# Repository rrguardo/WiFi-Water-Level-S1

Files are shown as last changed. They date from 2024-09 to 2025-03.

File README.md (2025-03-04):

# WiFi Water Level S1

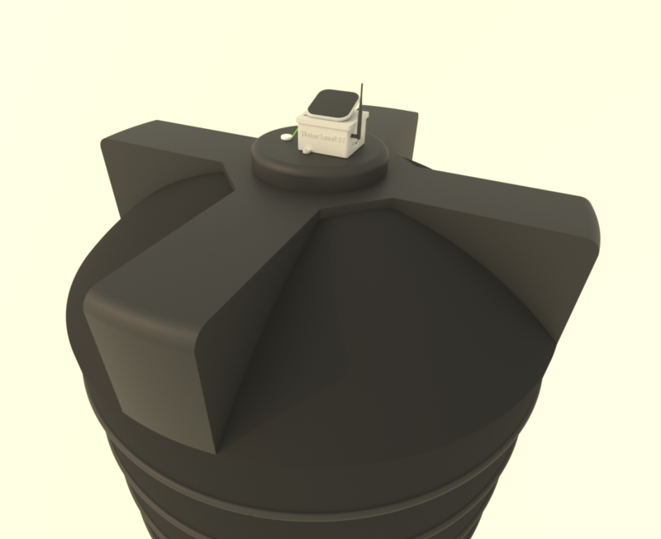
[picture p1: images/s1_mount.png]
WiFi Water Level S1


The **WiFi Water Level S1** is an advanced water level monitoring device designed to deliver precise
measurements for various applications, including tanks, wells, and reservoirs. 
Utilizing WiFi connectivity, it enables real-time monitoring and management of water levels from anywhere via a 
smartphone or computer. Powered by **solar energy**, the device is completely
wireless and autonomous. 

The system is cloud-connected, requiring an internet connection, and is designed for reliable, continuous operation.
For more details, refer to the [full features page](https://waterlevel.pro/products/WiFi-Water-Level-S1).

Additionally, it integrates seamlessly with the [WiFi Smart Water Pump Controller S1](https://github.com/rrguardo/WiFi-Smart-Water-Pump-Controller-S1), allowing for 
automatic control of a water pump based on the sensor's data. This integration enhances the system's 
efficiency by automating water management processes.

The project is open source and open hardware, licensed under GPLv3. All hardware, software, and
3D printable components were designed from scratch by me, **Raul Rodriguez Guardo**, and are released 
under the GPLv3 license, allowing for free use and modification.

<div style="display: flex;">
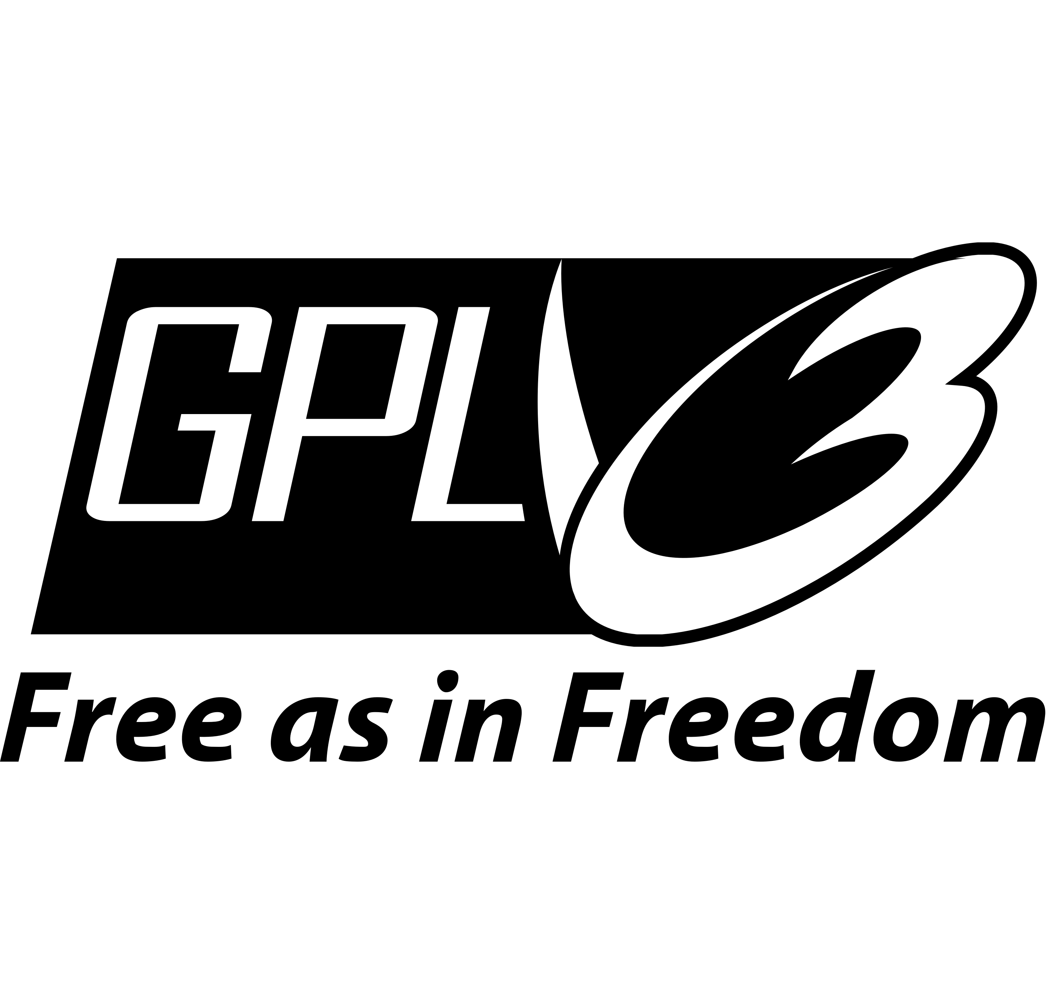
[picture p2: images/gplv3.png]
  
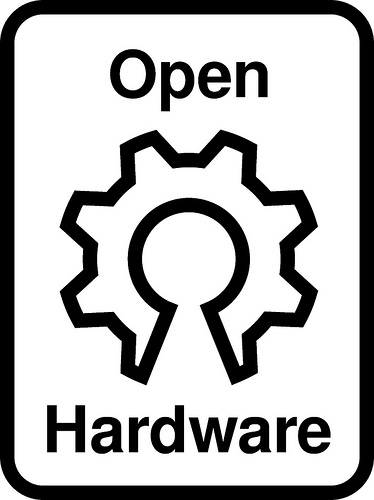
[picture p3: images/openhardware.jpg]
Imagen 1
  
</div>

[Real S1 Device Demo](https://waterlevel.pro/device_info?public_key=demo)

<div style="display: flex;">
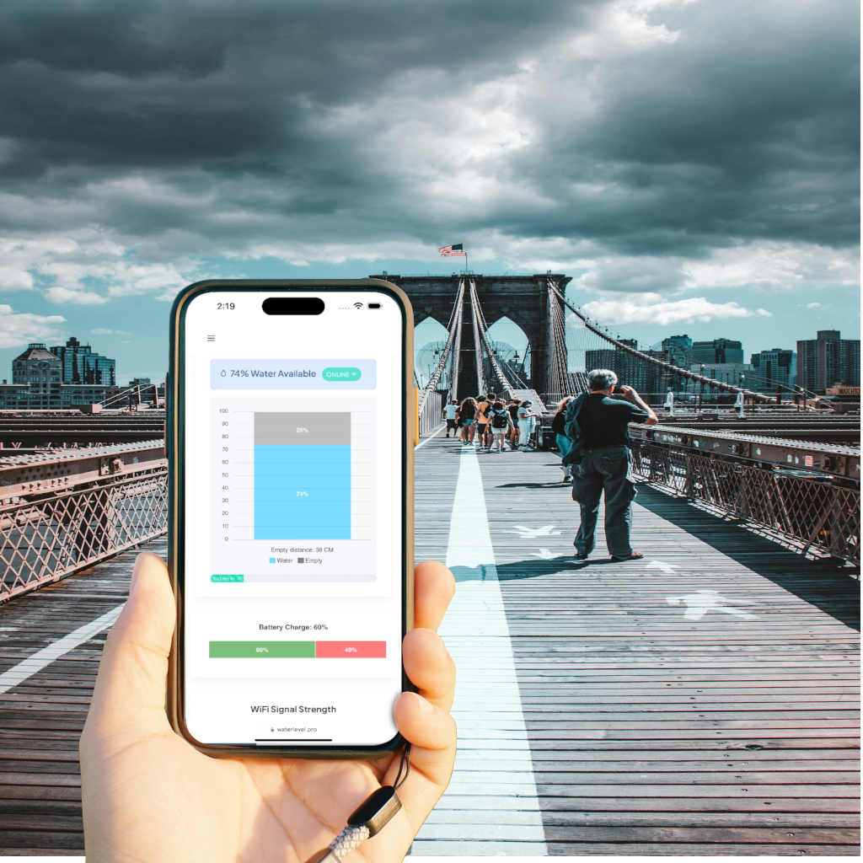
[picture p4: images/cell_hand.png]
  
</div>

### Device Compatible Sensors

* All **HCSR04** sensors family, that can work with **3.3V**
  *   **AJ-SR04M** recommended for water tanks or places of extreme humidity.
  *   **RCWL-1670** is compatible, but will need special waterproof case, if will be placed inside water tanks. 
* UART Distance sensors , that can work with **3.3V** (Not tested yet, experimental)
  *   **A02YYUW** recommended for water tanks or places of extreme humidity. 
  Offer a range of 3-450 CM, with an small 3 CM blind area.

**Note:** UART sensors have not been tested with this device yet and are currently in the experimental phase. 
To enable UART (A02YYUW), add or uncomment `#define UART_SENSOR`. Refer to the schematic or the PCB layout image 
to identify the RX/TX pins.

### Device Compatible Solar Panels

* Tested with 5.5 V, 130 mA Solar Panel (5.5V 130mA 72x72mm) https://www.aliexpress.us/item/3256804502745527.html using D1 5V zener. 
* Don't use solar panels that pass the 250 mA or 5.5V

## DIY Guide

For a detailed guide on how to build this project, check out the full tutorial at [Instructables](https://www.instructables.com/Build-Your-Own-DIY-WiFi-Water-Level-Sensor-S1/).

## Microcontroller Software

[ArduinoIDE INO File](WiFiWaterLevelS1/WiFiWaterLevelS1.ino)

This devide use ESP32-C3 microcontroller can use Arduino IDE to flash/upload microcontroller code, using **ESP32C3 Dev Module** as board.

[Download Latest Firmware Builds Here](WiFiWaterLevelS1/firmwares/)

## Server Side Minimal Sample in Python

Note [WaterLevel.Pro](https://waterlevel.pro/) offer a more advanced server side service free, 
but you can make your own server using the sample provided as a minimal sample. 

[Server sample that process and show sensor data](demo_server.py)

Pending TODO: Improve the opensource Server Side Minimal Sample UI.

---

## Hardware part at OSHWLab

[SunBuddy-C3 Module](https://oshwlab.com/rrguardo83/water-level-.pro-s1-v2)

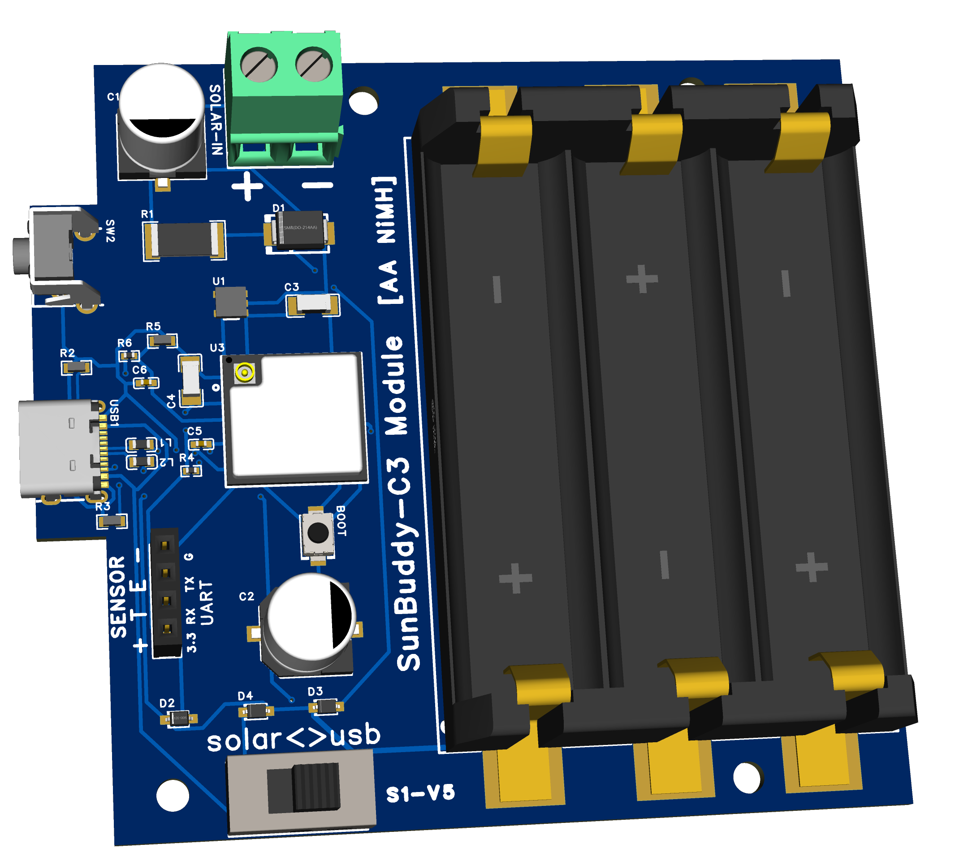
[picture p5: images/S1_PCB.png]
S1 PCB


### Where buy the PCB board?
[At EasyEDA project](https://waterlevel.pro/short/sunbuddy)
editor click **Order** menu.

### PCB Component Roles Diagram

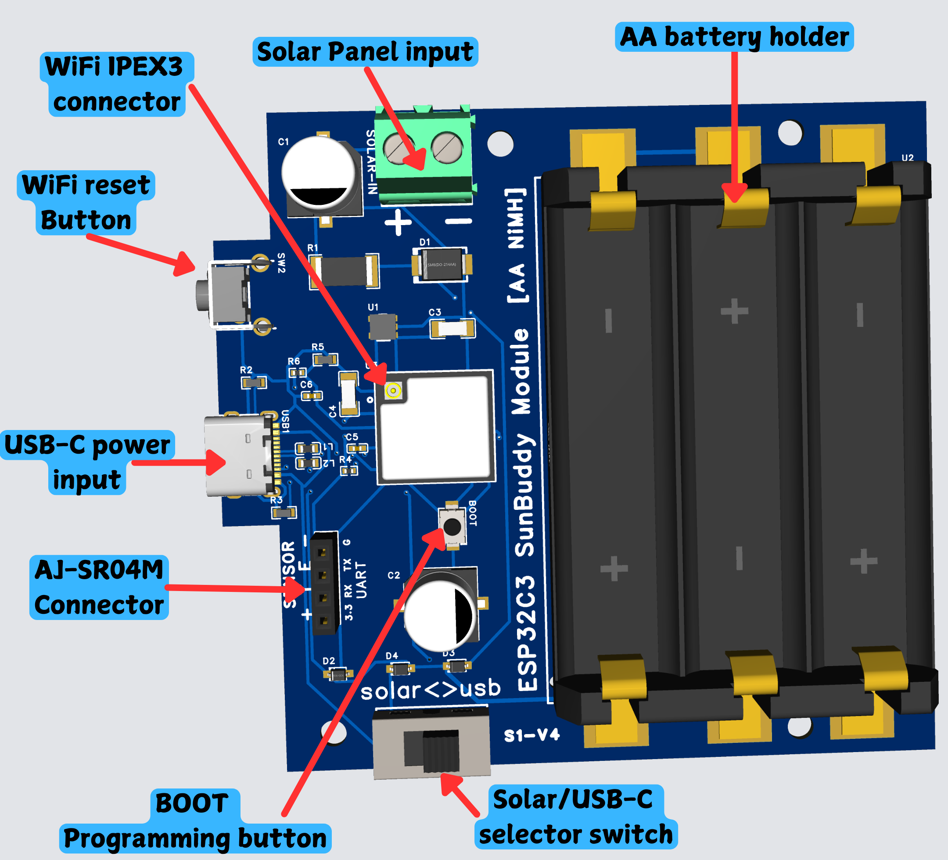
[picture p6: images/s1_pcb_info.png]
S1 PCB Features


---
## FreeCad 3D printable case components

[3D printable case components](3dcase)

For more details about important 3d printing recommendations 
 [read this tips](3dcase/3DPrintReadme.md).

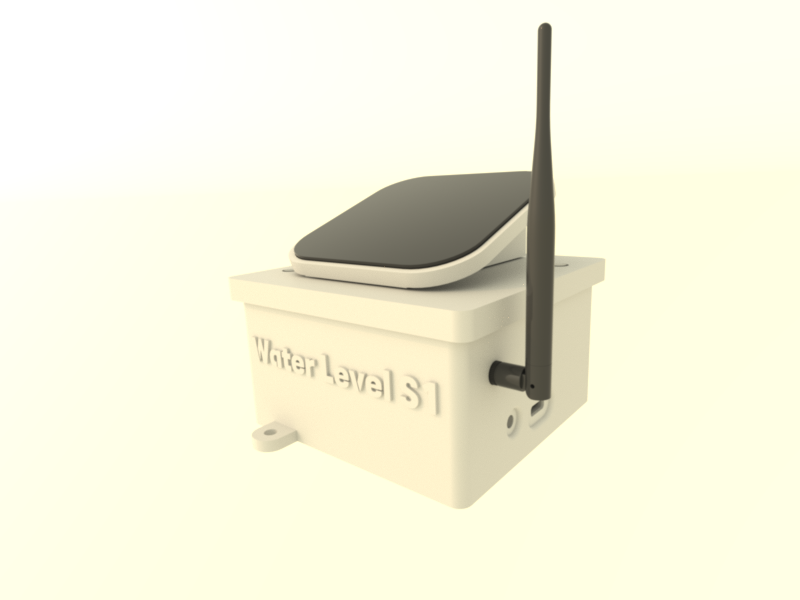
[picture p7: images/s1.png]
s1 open


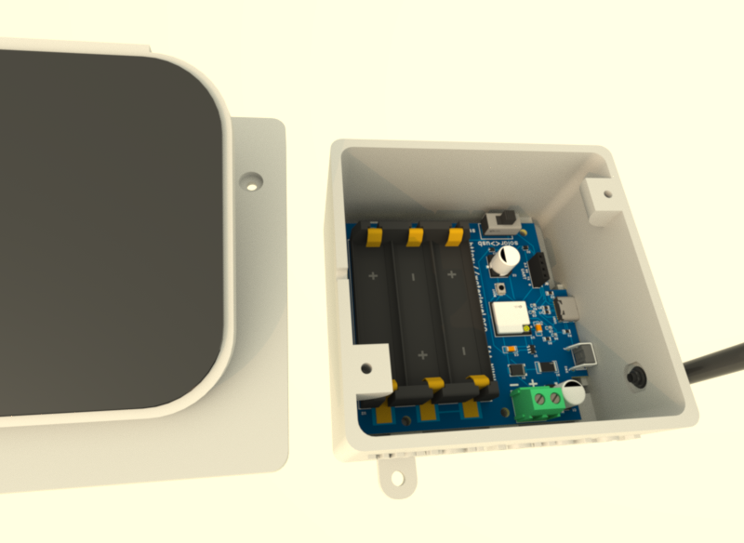
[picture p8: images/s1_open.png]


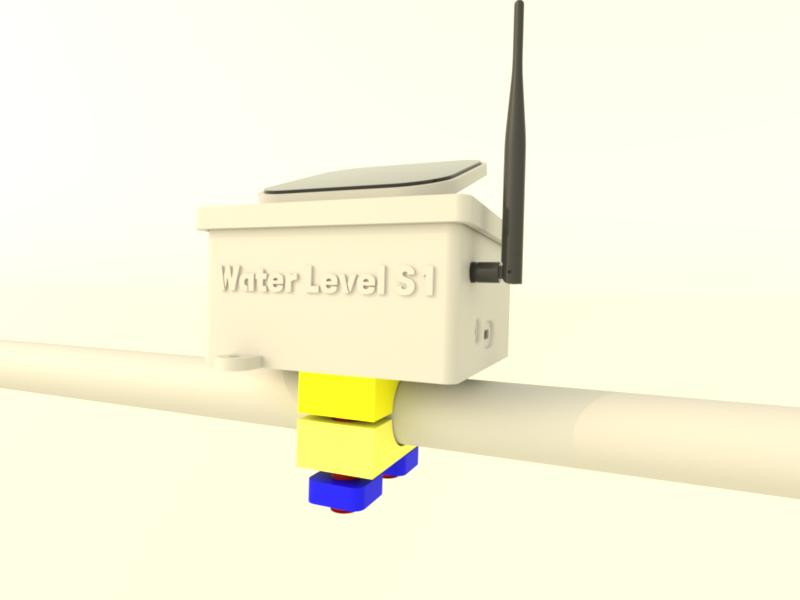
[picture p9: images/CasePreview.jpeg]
Top View


Bottom View

### No 3D Printer? No Problem! Easily Print Parts Using Online 3D Printing Service

| **3D Print Provider** | **Recommended Materials for Outdoors** | **Approximate Price** | **Print Quality** | **Delivery Options** | **Comments** |
|---|---|---|---|---|---|
| **JLCPCB (JLC3DP)** | Nylon (PA12) | Low to Medium | High for resin and MJF | International, economical | Great value for money, lacks PETG or ASA options |
| **Shapeways** | Nylon, Stainless Steel, Aluminum | Medium to High | Very high, detailed | International, fast | Ideal for high-detail projects and outdoor durable parts |
| **Sculpteo** | Nylon (PA12), Aluminum, Carbon-Reinforced Nylon | Medium | High | International, fast options | Wide range of materials, good for durable prototypes |
| **3D Hubs** | PETG, ABS, Nylon, Carbon Fiber-Reinforced Materials | Medium | High, varies by local provider | International, varies | Global network, quality and delivery times vary by provider|
| **Craftcloud** | PETG, Nylon, ASA, Carbon Fiber-Reinforced Materials | Medium | High, varies by provider | International, varies | Service aggregator, good price comparison across providers |
| **Materialise** | Nylon (PA12), Carbon-Reinforced Nylon, Metals | High | Very high, industrial focus | International, fast | Focus on industrial and professional applications |
| **Xometry** | Nylon, ABS, PETG, Aluminum, Carbon-Reinforced Nylon | Medium to High | Very high, professional focus | International, fast | Ideal for custom manufacturing and durable industrial parts|

Choose durable materials like **PETG** for outdoor use, and set **infill at 60%** or higher for added strength. Just upload the 3D files and get everything printed and shipped to you!

---
## Mount options samples
### Pipe mount
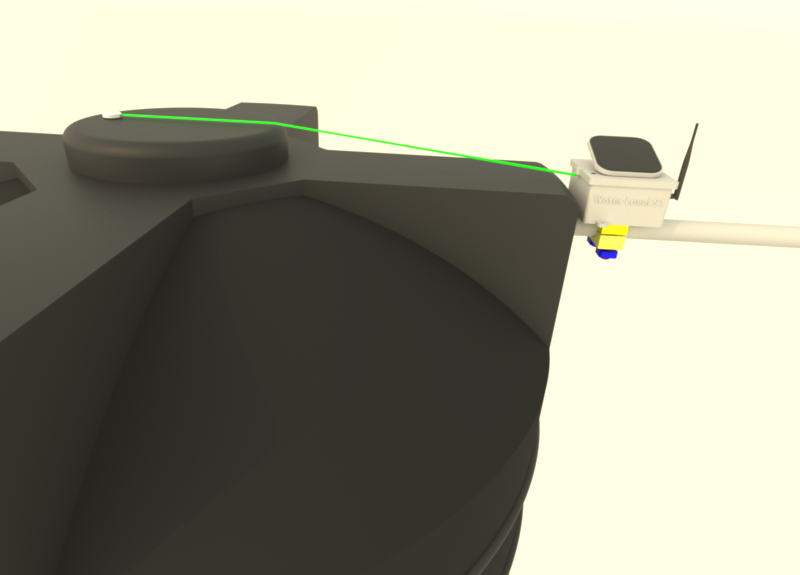
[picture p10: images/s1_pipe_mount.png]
Pipe Mount


### Water tank lid mount
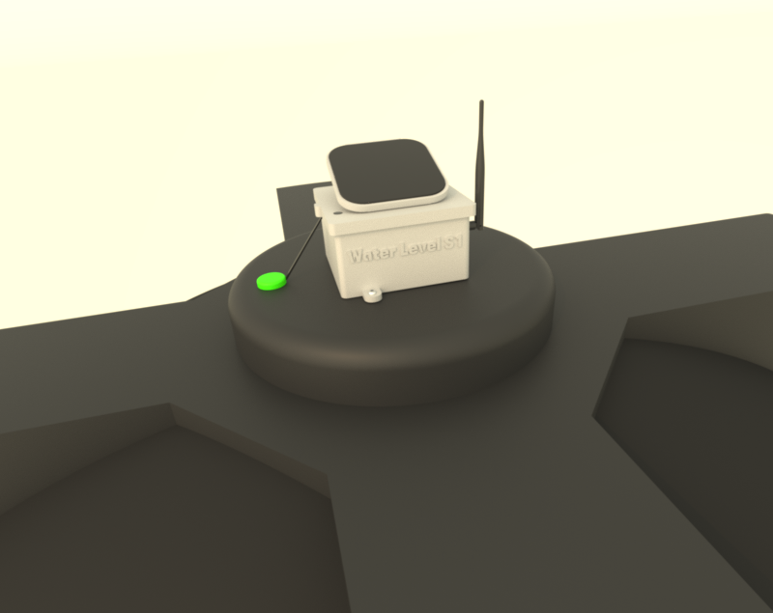
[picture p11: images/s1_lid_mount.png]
Lid Mount


---
## User Installation Manual

The [installation manual](https://waterlevel.pro/manuals/WiFi-Water-Level-S1) provides 
detailed instructions on setting up the WiFi Water Level S1. 
Be sure to [read all instructions](https://waterlevel.pro/manuals/WiFi-Water-Level-S1) 
carefully before proceeding with the installation to ensure proper 
setup and functionality.

[WiFi Water Level S1, Installation Manual](https://waterlevel.pro/manuals/WiFi-Water-Level-S1)

---

## What parts are opensource?

* All the hardware part
  * Electronics part: PCB, schematic.
  * Printable 3D Case
* Firmware software
* [Server sample that process and show sensor data](demo_server.py)

The server side implementation at https://waterlevel.pro/ (cloud services) that use the device are not 
included in this project or git repo and are not opensource.

---

## Next TODO:

* Add basic DIY Guide
* Improve the opensource server sample
  * UI
* ...

---

## Important Disclaimer

> **Disclaimer:**  
This open-source electronics project/device is provided strictly for experimental, educational, and developmental purposes. It is offered "as is," without any warranties, express or implied. This includes, but is not limited to, implied warranties of merchantability, fitness for a particular purpose, or non-infringement.
> 
Users are solely responsible for ensuring that the use of this device complies with local laws, regulations, and safety standards in their region.

---

<div align="center">
  <h5>Designed in the Dominican Republic 2024-2025</h5>
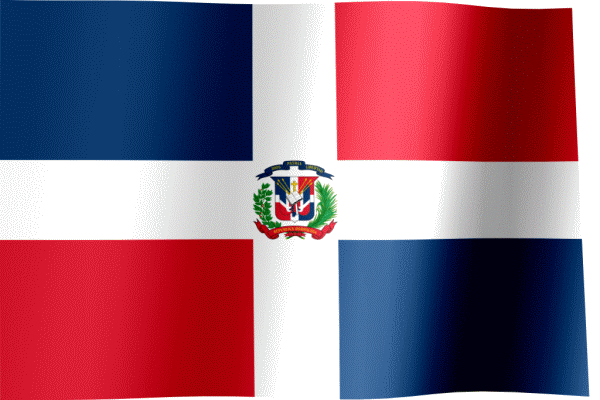
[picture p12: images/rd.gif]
RD
  
</div>

---

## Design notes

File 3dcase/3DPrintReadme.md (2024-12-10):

# Recommendations for Printing an Outdoor Case

To ensure that a case designed for outdoor use is durable and resistant to environmental conditions, follow these guidelines for various types of 3D printers and filaments:

## FDM Printers with PETG

**PETG** is a great choice for outdoor applications due to its resistance to UV light and moisture. Follow these settings for optimal results:

### Layer Height
- Use a smaller layer height (e.g., 0.2mm) to ensure finer details and better strength.

### Infill Density
- Set the infill density to at least 50% to provide adequate strength and durability. For high-impact areas, consider increasing to 100%.

### Wall Thickness
- Increase wall thickness (e.g., 4 to 6 walls) to enhance the structural integrity of the case and improve resistance to physical impacts.

### Cooling
- Use minimal cooling to prevent warping and ensure strong layer bonding.

### Annealing
- Consider annealing the printed case to improve strength and durability. This process can enhance PETG’s resistance to environmental factors.

## Other Types of Printers and Filaments

### SLA/DLP Printers
- **Resin**: Use UV-resistant resin for better durability against sunlight and weather conditions.
- **Settings**: Follow manufacturer recommendations for curing times and temperatures to ensure optimal print quality and resistance.

### SLS Printers
- **Nylon (PA)**: Use nylon, as it offers good resistance to UV light and moisture. It is also known for its toughness.
- **Settings**: Follow specific printer and material guidelines for temperature and print settings.

### High-Performance Materials
- **ABS**: For a more traditional choice, ABS can be used if UV resistance is not a primary concern, but it may require additional post-processing for outdoor use.
- **Polycarbonate (PC)**: This material provides excellent impact resistance and can withstand extreme temperatures, making it suitable for harsh environments.

## Sealing and Assembly Tips

- **Silicone Adhesive**: Use silicone adhesive or a glue gun with silicone sticks to seal and protect the case. Apply silicone to seal connectors, buttons, cables, and other openings to prevent moisture ingress and improve overall durability.
- **Sealing Joints**: Ensure that all seams and joints are properly sealed with silicone to protect against water and humidity.

## General Tips
- **Post-Processing**: Consider applying a UV-resistant coating or paint to further enhance protection against environmental elements.
- **Sealing**: Ensure that all seams and joints are properly sealed to prevent water ingress.

By following these recommendations, you can create a durable and resilient case suitable for outdoor environments.

---

# Recommendation for Printing Screws with PETG

To achieve the best results when printing 11mm diameter screws using FDM printers or other types of 3D printers with PETG filament, follow these guidelines:

## Layer Orientation

- Print the screws in a vertical orientation to ensure better definition of the threads and channels. This position can also facilitate faster printing with a 0.6mm nozzle, which is capable of producing high-quality prints efficiently.

## Layer Height

- Use a smaller layer height (e.g., 0.1mm to 0.2mm) for finer details and improved layer adhesion.

## Infill Density

- Set the infill density to 100% to ensure maximum strength and durability of the screw.

## Wall Thickness

- Increase the wall thickness (e.g., 4 to 6 walls) to enhance the structural integrity of the screw and prevent layer separation.

## Cooling

- Minimize or turn off the cooling fan to prevent layer delamination and ensure strong layer bonding.

## Annealing

- Consider annealing the printed screws to further improve their strength and layer bonding. This process enhances the mechanical properties of PETG, making the screws more durable.

## Nozzle Size

- A 0.6mm nozzle can be used to print the screws quickly and effectively while still achieving good thread definition. Ensure the print temperature is increased to improve layer adhesion and overall quality.

By following these guidelines, you can enhance the performance, durability, and precision of 11mm diameter screws printed with PETG filament.

---

## Other details
*  Solar lid is divided in 2 parts **SolarLid.stl** and **SolarSupportV2.stl**, use silicon glue to join the 2 parts.
* ...

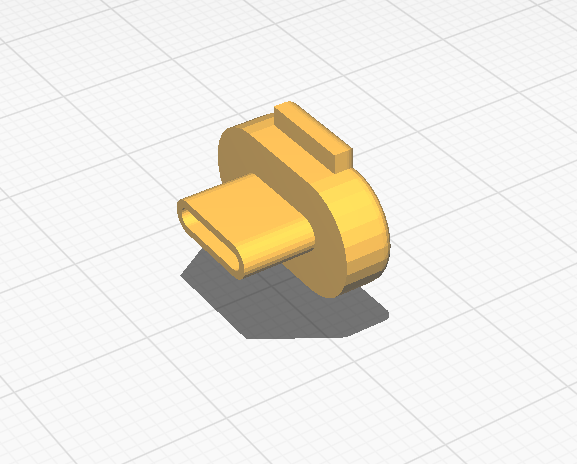
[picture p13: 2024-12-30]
images/usbc_cap.png

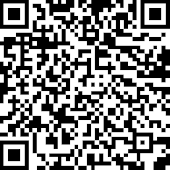
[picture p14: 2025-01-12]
images/eth_donations.png

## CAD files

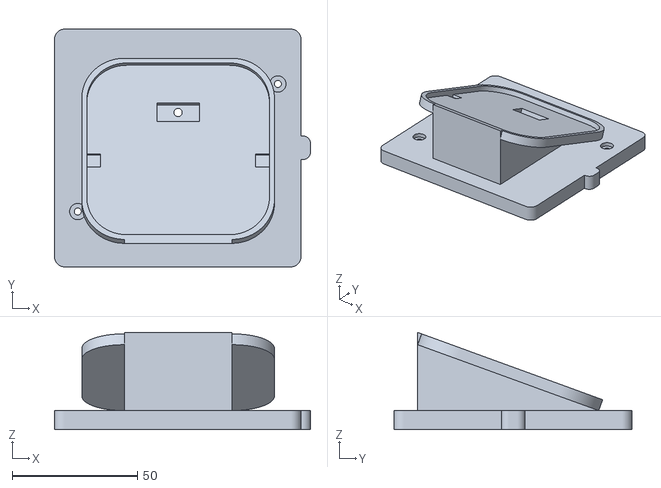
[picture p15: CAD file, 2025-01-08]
3dcase/LidSolarFusion.stl
102.3 x 95.0 x 38.8

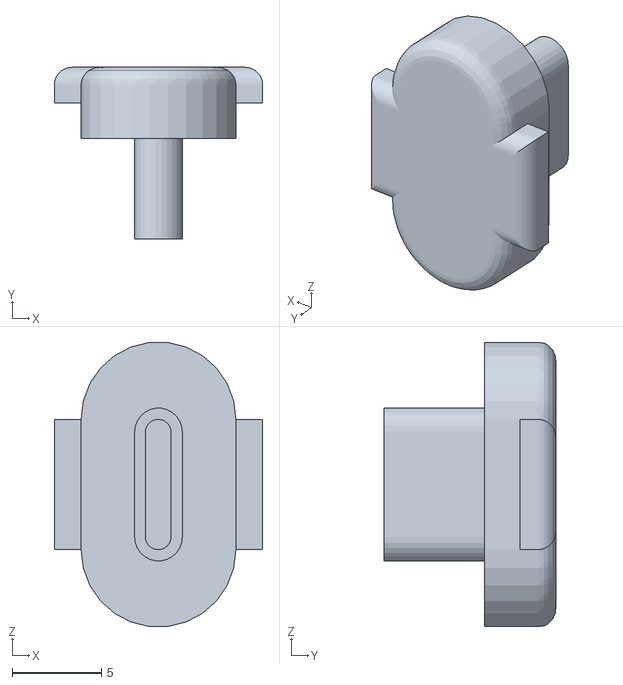
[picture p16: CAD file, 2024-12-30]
3dcase/USBC_CAP.stl
11.7 x 9.60 x 15.9

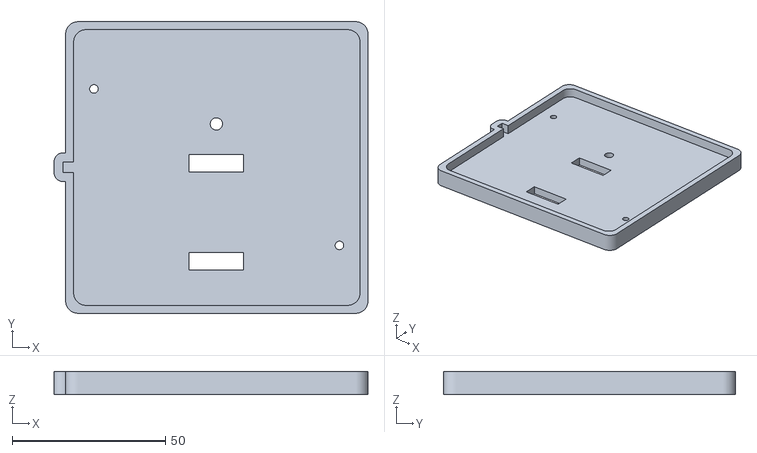
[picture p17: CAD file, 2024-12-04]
3dcase/SolarLid.stl
102.3 x 95.0 x 7.60

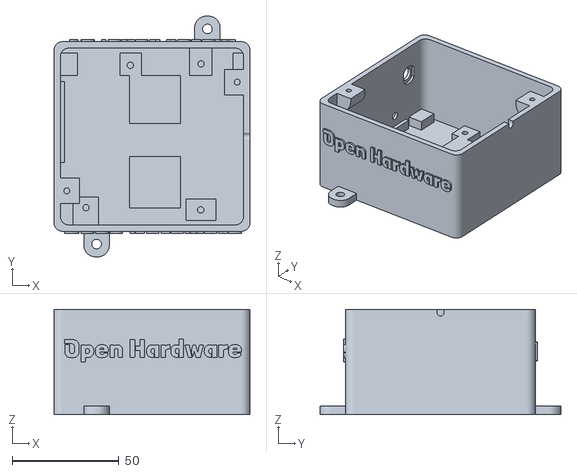
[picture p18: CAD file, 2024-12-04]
3dcase/Base.stl
92.0 x 113.0 x 49.4

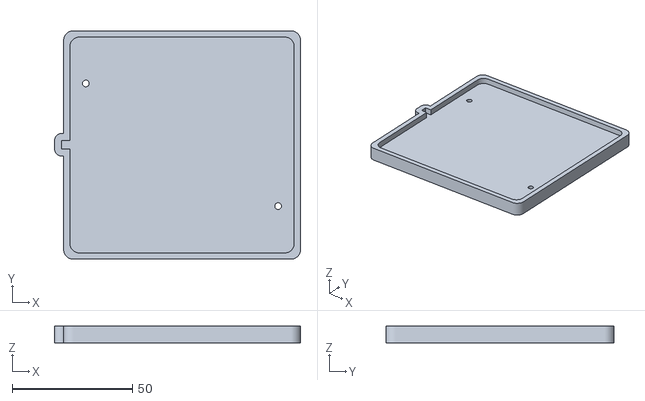
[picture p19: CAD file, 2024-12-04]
3dcase/LidUSBPower.stl
102.3 x 95.0 x 7.00

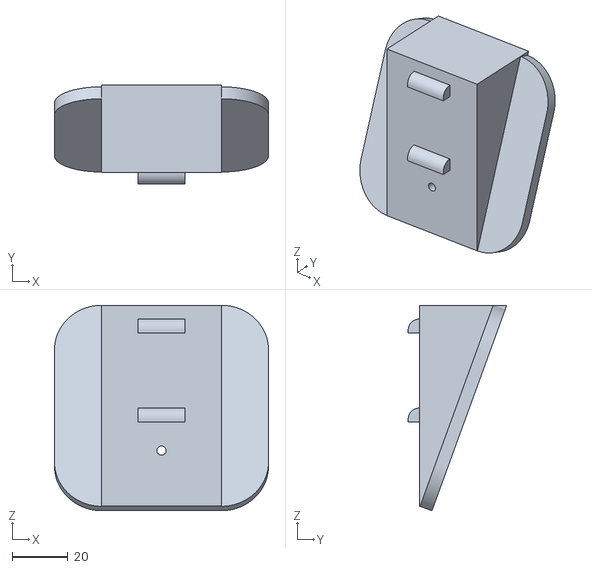
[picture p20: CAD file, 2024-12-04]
3dcase/SolarSupportV2.stl
77.0 x 35.5 x 73.9

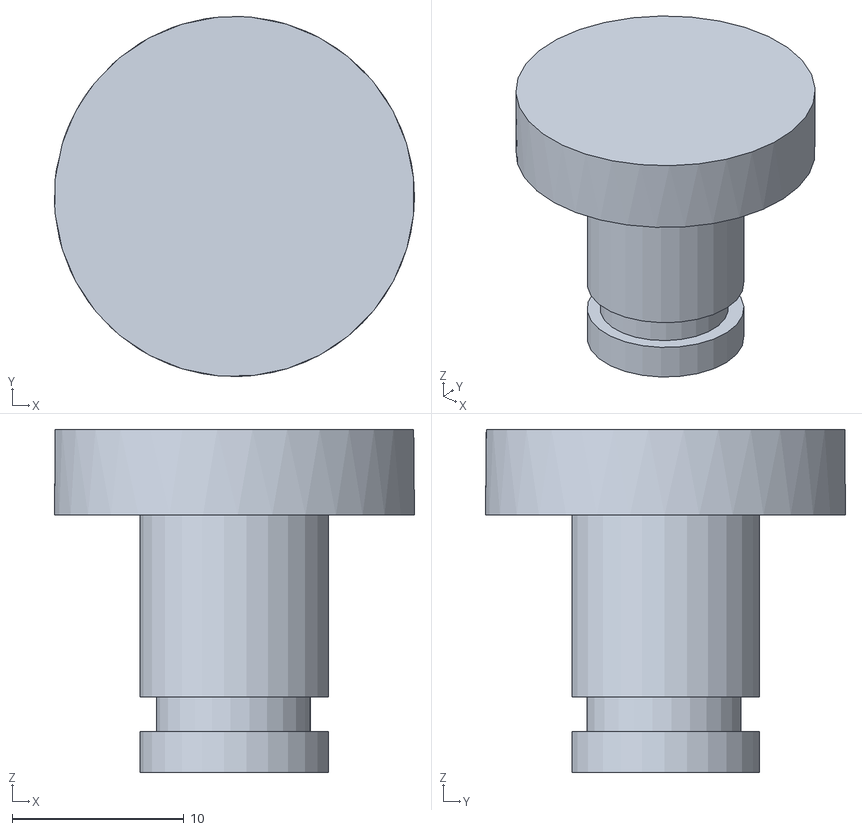
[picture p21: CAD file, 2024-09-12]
3dcase/WaterTankCordCap11mm.stl
21.0 x 21.0 x 20.0

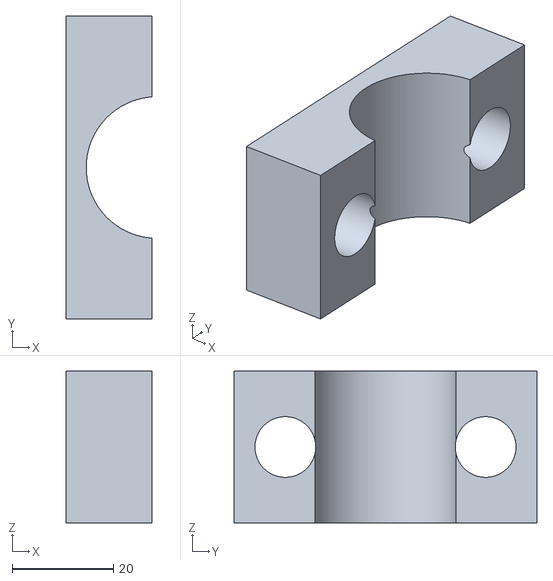
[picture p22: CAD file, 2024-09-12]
3dcase/S1MountFor27mmPipe.stl
17.0 x 59.9 x 30.0

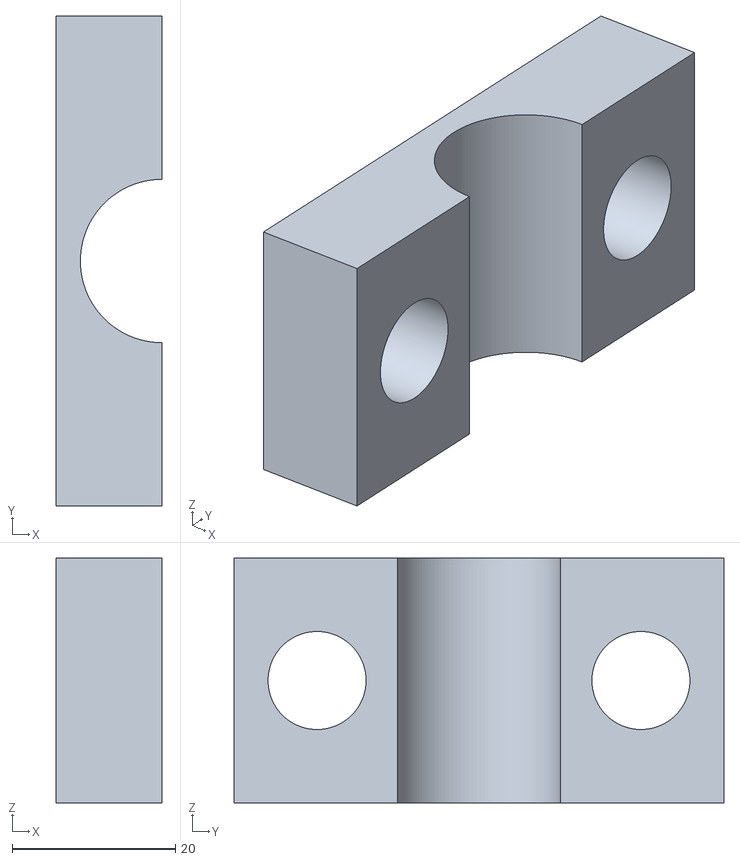
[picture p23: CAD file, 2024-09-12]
3dcase/S1Mount.stl
13.0 x 60.0 x 30.0

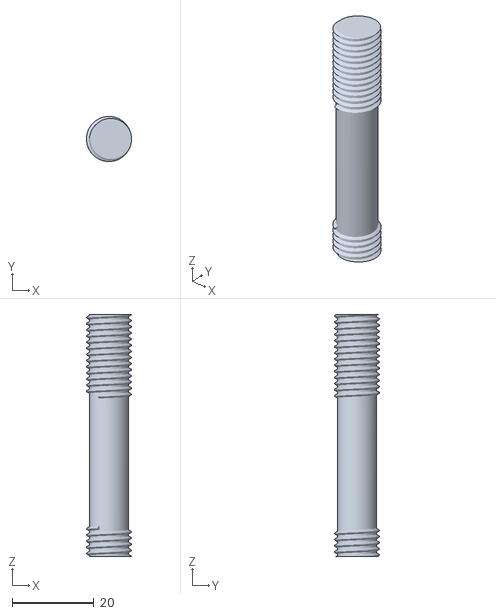
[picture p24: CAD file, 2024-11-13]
3dcase/GripScrewFor27mmPipe.stl
11.0 x 11.0 x 59.1

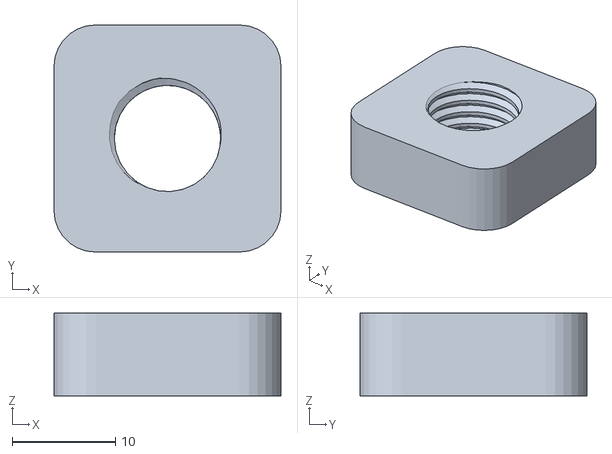
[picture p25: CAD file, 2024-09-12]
3dcase/Nut.stl
22.0 x 22.0 x 8.00

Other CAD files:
3dcase/WaterTankCordCap12mm.stl

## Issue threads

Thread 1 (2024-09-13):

High power consumption while sleep at ESP32C3 model ESP32-C3-MINI-1U-H4

rrguardo, 2024-09-13:
This specific version of ESP32-C3 (ESP32-C3-MINI-1U-H4) behave distinct to  ESP32-C3 mini dev-board, at deep-sleep mode it consuming 20 mA and draining batteries fast, while ESP32-C3 mini dev-board using same microcontroller code consume under 1 mA.

The result is that batteries get exhausted faster.

ESP32-C3 mini dev-board used Image >>
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

ESP32-C3-MINI-1U-H4 used image
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

Closed 2024-09-18.

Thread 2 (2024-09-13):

The clamping screws break easily

rrguardo, 2024-09-13:
When you tighten the plastic holding screws a little, they break at the joint between the 3D printing layers.

rrguardo, 2024-09-13:
The solution here is increment the printing temperature at maximum possible, if don't work try annealing or print the screws horizontal.

 [read this tips](https://github.com/rrguardo/WiFi-Water-Level-S1/blob/main/3dcase/3DPrintReadme.md).

Closed 2024-09-13.

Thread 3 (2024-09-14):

The new SMD components or PCB routing are not working properly

rrguardo, 2024-09-14:
The new hardware version (v2) is behaving unstable and present some problems not observed at (v1)

* ADC voltage divisor require adjustment
* Apparently a huge power leak compared to older version
> * Device almost only work where sun is present
> * After few days, it only works when voltage and charge is almost full (~4 v)
* Device power by USBC is working properly, the problem is only present when swap to solar/batteries

rrguardo, 2024-09-16:
Testing some ideas here to solve the problem:

1) Swap sleep function from **ESP.deepSleep** to **esp_deep_sleep**
2) Indirect ADC adjustment, setting **LowVoltage** from **3.3v** to **3.5v**
3) Replace AA NiMH batteries for new ones (assuming some old damaged batteries was part of the problem)

rrguardo, 2024-09-17:
Based in api logs, first day, with batteries fully charged, the device worked continually until 7 AM. Then after 7 AM, it reach min voltage protection 3.5v and started to send sensor data more delayed until the sun appears near 8:25 AM and resume normal working and start to charge batteries.

Closed 2024-09-18.

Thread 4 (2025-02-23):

Can you please support a02yyuw ultrasonic sensor?

Arakistech, 2025-02-23:
Can you please support a02yyuw ultrasonic sensor?

rrguardo, 2025-02-24:
Yes sure, looks a good sensor. Will schedule add it in next updates, probably in 2 or 3 weeks could be ready

rrguardo, 2025-02-27:
UART sensors support added, uncomment the `#define UART_SENSOR` to swap to UART, see the schematic or PCB roles image to identify RX/TX pins.

[PCB Features](https://github.com/rrguardo/WiFi-Water-Level-S1/blob/main/images/s1_pcb_info.png)

If someone can test it and detect any problem please report it.

Arakistech, 2025-02-28:
Thank you for your great job. I am afraid that the current consumption of this particular sensor is too high to be powered constantly. I think it´s power should be switched on/off with a GPIO pin.

Regards

Closed 2025-02-27.

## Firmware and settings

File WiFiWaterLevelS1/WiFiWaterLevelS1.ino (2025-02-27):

/*
 * This file is part of WiFi Water Level S1 project.
 *
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
 * You should have received a copy of the GNU General Public License
 * along with this program. If not, see <https://www.gnu.org/licenses/>.
 */

// IDE and Board
// Arduino Framework version: 2.3.4
// Arduino Board Module: ESP32C3 Dev Module
// Board: ESP32-C3-MINI-1U-H4
// Board Manager URL: https://arduino.esp8266.com/stable/package_esp8266com_index.json

// Libraries used:
// WiFiManager by tzapu version: 2.0.16-rc.2

// Usage DOC
//
// * To Disable live updates set  DEV_MODE = false
// * To enable UART (A02YYUW) sensor uncomment >> #define UART_SENSOR   this will disable HCSR04 family sensors
//


#include <Arduino.h>

#include <WiFiManager.h>
#include <HTTPClient.h>
//#include "certs.h"

#include <nvs_flash.h>

#include <String.h>
#include "driver/adc.h"
#include "esp_sleep.h"

#include <Update.h>

#include "esp_wifi.h"


// uncomment line below to use UART sensors like A02YYUW (This functionality has not been tested yet.)
//#define UART_SENSOR


#ifdef UART_SENSOR
  #include <HardwareSerial.h>

  // Defining the UART pins for the A02YYUW sensor
  #define A02YYUW_RX_PIN 20  // GPIO20 connected to the sensor TX
  #define A02YYUW_TX_PIN 21  // GPIO21 connected to the sensor RX
  // Initialize the HardwareSerial port
  HardwareSerial A02YYUW_Serial(0);
#endif



//#define DEBUG  // Comment this line to disable serial prints

#define EMAIL_MAX_LENGTH 128  // Nuevo tamaño para el email


// DEV MODE allow app update remote
const bool DEV_MODE = true;
const char* firmwareUrl = "https://waterlevel.pro/static/fw";
int FIRMW_VER = 22;

int32_t rssi = 0;


const int pinVoltageInput = 2;  // Using ADC1_CH2 en GPIO2

// Define the pins for the HCSR04 sensor
const int trigPin = 20;
const int echoPin = 21;

// Button Pin (FLASH button)
const int pinBoton = 10;

enum ConfigStatus {
  SCREEN,
  WIFI,
  SCREEN_WIFI,
  WIFI_SETUP,
  MIN_LEVEL,
  SELECT_MODE
};

ConfigStatus CurrentStatus = WIFI_SETUP;
int last_distance = 0; // used to set min level

int WIFI_POOL_TIME = 30; // wifi usage pool time in seconds
int SONIC_POOL_TIME = 3; // sonic usage pool time in seconds

int last_wifi_usage = 0;
int last_sonic_usage = 0;
unsigned long tiempoArranque;
unsigned long tiempoBateria = 0;


// If will use a custom private server, replace this with the URL you want to send the sensor info. See **demo_server.py** for a free open source server sample in python-flask
// Waterlevel.pro offers free server services with a sensor info update time of up to 120 seconds.
const char* host_url = "https://api.waterlevel.pro/update";


const char* host_link_url = "https://api.waterlevel.pro/link";

char api_key[128] = "-";  //  PRIVATE KEY HERE // "-" none-null-api-key
// use value "-" for automatic api key setup
// or manually generate and use new key in developer zone at https://waterlevel.pro/settings   https://waterlevel.pro/add_sensor

const char* WIFI_NAME = "WaterLevelProSetup";
const char* WIFI_PASSW = "1122334455";
char email[EMAIL_MAX_LENGTH] = "-";  // Variable to store email
 
WiFiManager wm;
// Set custom email parameter
WiFiManagerParameter custom_email("email", "Enter Email", email, EMAIL_MAX_LENGTH, "type='email' required placeholder='example@example.com'");


nvs_handle_t my_nvs_handle;

void setup() {
  // put your setup code here, to run once:

  // ADC init
  adc1_config_width(ADC_WIDTH_BIT_12);
  adc1_config_channel_atten(ADC1_CHANNEL_2, ADC_ATTEN_DB_11);  // Configurar atenuación del canal
  analogReadResolution(12);  // Establecer resolución del ADC a 12 bits
  adcAttachPin(pinVoltageInput);  // Adjuntar el pin al canal ADC
  UnderVoltageProt(true, 0); //check undervoltage

  Serial.begin(115200);

  #ifdef UART_SENSOR
    // Iniciar la comunicación UART con el sensor
    A02YYUW_Serial.begin(9600, SERIAL_8N1, A02YYUW_RX_PIN, A02YYUW_TX_PIN);
  #endif

  #ifdef DEBUG
    Serial.println("Setup Started!");
  #else
    delay(5);
  #endif

  tiempoArranque = millis();
  tiempoBateria = 0;


  // Init memory flash
  esp_err_t err = nvs_flash_init();

  if (err == ESP_ERR_NVS_NO_FREE_PAGES || err == ESP_ERR_NVS_NEW_VERSION_FOUND) {
      // NVS partition was truncated and needs to be erased
      // Retry nvs_flash_init
      ESP_ERROR_CHECK(nvs_flash_erase());
      err = nvs_flash_init();
  }
  ESP_ERROR_CHECK( err );
  err = nvs_open("storage", NVS_READWRITE, &my_nvs_handle);
  if (err != ESP_OK) {
    
    #ifdef DEBUG
      Serial.println("Error opening nvs handler");
    #else
      delay(5);
    #endif

  } else {
    #ifdef DEBUG
      Serial.println("Done opening nvs handler");
    #else
      delay(5);
    #endif
  }

  //load_email();

 
  // Add parameter to WiFiManager
  wm.addParameter(&custom_email);
  // Set config save callback
  wm.setSaveConfigCallback(saveConfigCallback);

  load_private_key();
  load_settings();
  

  if(CurrentStatus == WIFI_SETUP){
    SetupResetWifi();
  }

  #ifndef UART_SENSOR
    // Set the trigger pin as an output and the echo pin as an input
    pinMode(trigPin, OUTPUT);
    pinMode(echoPin, INPUT);
  #endif

  // Configuramos el pin del botón como entrada
  pinMode(pinBoton, INPUT_PULLUP);
  // Asociamos la función botonPresionado() al pin del botón
  attachInterrupt(pinBoton, botonPresionado, FALLING);

}

void saveConfigCallback() {
  Serial.println("Enter saveConfigCallback");
  // Placeholder for additional code to handle saving to persistent storage, if needed

  // Guardar el email en EEPROM
  const char *newEmail = custom_email.getValue();
  strncpy(email, newEmail, sizeof(email) - 1); // Copiar el nuevo valor
  email[sizeof(email) - 1] = '\0'; // Asegurar que termina con '\0'


  if(myStrlen(email) >= 7 ){

    #ifdef DEBUG
      Serial.print("Email to linked: ");
      Serial.println(email);
    #else
       delay(5);
    #endif
  }else{
    Serial.print("Invalid email: ");
    Serial.println(email);
    strcpy(email, "-");
  }

}

int myStrlen(const char* str) {
  int len = 0;
  while (*str != '\0') {
    len++;
    str++;
  }
  return len;
}


void load_private_key(){

  size_t required_size = 0;
  nvs_get_str(my_nvs_handle, "PrivateKey", NULL, &required_size);
  if (required_size != 0 and required_size > 10) {
    char* tmp_key = (char*)malloc(required_size);
    nvs_get_str(my_nvs_handle, "PrivateKey", tmp_key, &required_size);
    strcpy(api_key, tmp_key);  
    free(tmp_key);

    #ifdef DEBUG
      Serial.print("Private Key loaded from memory: ");
      Serial.println(api_key);
    #else
       delay(5);
    #endif

  }else if(strcmp(api_key, "-") != 0){
    nvs_set_str(my_nvs_handle, "PrivateKey", api_key);
    nvs_commit(my_nvs_handle);

    #ifdef DEBUG
      Serial.print("Private Key loaded from code: ");
      Serial.println(api_key);
    #else
       delay(5);
    #endif
  }

  if(myStrlen(api_key) < 10 && CurrentStatus != WIFI_SETUP){
    #ifdef DEBUG
      Serial.print("ERROR: Short API KEY: ");
      Serial.println(api_key);
    #else
       delay(5);
    #endif
    esp_system_abort("restart_after_wakeup");
  }


}


void restart_after_wakeup()
{
  // Hacer un restart
  //esp_system_abort("restart_after_wakeup");
  esp_system_abort("restart_after_wakeup");
}

float UnderVoltageProt(bool is_setup, int tryNum){
  const float referenciaADC = 8.39;  // Ajustar según la referencia del ADC
  float LowVoltage = 3.5; // This will trigger protection

  // Realizar una medición ADC
  int lectura_adc = analogRead(pinVoltageInput);

  // Convertir el valor del ADC a voltaje
  float voltaje = (((float)lectura_adc + 40.2) / 474.0) +0.16;
  if(lectura_adc <= 400){
    voltaje = 5.0;
  }

  int delay_time = 1000;
  if(is_setup){
    delay_time = 10;
    //LowVoltage = LowVoltage + 0.08; //setup stage earn +0.7v while wifi-off
  }

  // Imprimir el resultado
  #ifdef DEBUG

  Serial.print("Valor ADC: ");
  Serial.print(lectura_adc);

  Serial.print(", Voltaje: ");
  Serial.print(voltaje, 2);  // Mostrar solo dos decimales
  Serial.println(" V");

  #else
       delay(5);
    #endif

  if(voltaje <= LowVoltage){
    Serial.println("Under Voltage Detected");
    if(tryNum < 3){
      non_lock_delay(delay_time);
      return UnderVoltageProt(is_setup, tryNum + 1);
    }

    if(is_setup){
      // Establecer la función de inicio de sueño profundo
      esp_set_deep_sleep_wake_stub(restart_after_wakeup);
      SleepSave(5*60); // 5 min-sleep-on-low-voltage
    }else{
      esp_system_abort("restart_after_wakeup");
    }
  }

  return voltaje;
}


void loop() {
  // put your main code here, to run repeatedly:

  // restart ESP after 30 minutes of continue usage to preven overflows, locks, ...++
  if(tiempoArranque > 30*60*1000){
    esp_system_abort("restart_after_wakeup");
  }

  float LastVoltage = UnderVoltageProt(false, 0); //check undervoltage

  last_distance = getDistance();

  ConnectWifi();
  for (int i2 = 0; i2 < 3; i2++) {
    if (HttpSendInfo(last_distance, LastVoltage)){
      break;
    }
    non_lock_delay(5000); // wait 5 seconds before next try
    WIFI_POOL_TIME = 300; // sleep 5 min. if not internet
  }
  

  wm.disconnect();
  WiFi.mode(WIFI_OFF);

  #ifdef DEBUG
    Serial.println("sleeping to save energy");
  #else
       delay(5);
    #endif

  SleepSave(WIFI_POOL_TIME);
  delay(5);

}


#ifndef UART_SENSOR
  // non UART distance function
  int getDistance() {
    // Trigger the sensor to send a pulse
    digitalWrite(trigPin, LOW);
    delayMicroseconds(5);
    digitalWrite(trigPin, HIGH);
    delayMicroseconds(15);
    digitalWrite(trigPin, LOW);

    // Measure the duration of the pulse on the echo pin
    long duration = pulseIn(echoPin, HIGH);

    // Calculate the distance based on the speed of sound (343 meters/second)
    // and the duration of the pulse
    int distance = duration * 0.0343 / 2;

    #ifdef DEBUG
      Serial.print("Distance: ");
      Serial.println(distance);
    #else
        delay(5);
      #endif

    return distance;
  }
#else
  // UART distance function
  int getDistance() {
    // Verificar si hay datos disponibles del sensor
    if (A02YYUW_Serial.available() >= 4) {
      // Leer los 4 bytes del marco de datos
      uint8_t data[4];
      for (int i = 0; i < 4; i++) {
        data[i] = A02YYUW_Serial.read();
      }
      // Verificar el byte de inicio
      if (data[0] == 0xFF) {
        // Calcular el checksum
        uint8_t checksum = (data[0] + data[1] + data[2]) & 0xFF;
        // Verificar el checksum
        if (checksum == data[3]) {
          // Calcular la distancia en centímetros
          int distance = ((data[1] << 8) | data[2]) / 10;
          return distance;
        }
      }
    }
    // Retornar 0 en caso de error
    return 0;
  }
#endif


// Función que se ejecutará cuando el botón se presione
ICACHE_RAM_ATTR void botonPresionado() {

  if(millis() < 1000) return;

  #ifdef DEBUG
    Serial.println("El botón está presionado");
  #else
       delay(5);
    #endif

  nvs_set_i32(my_nvs_handle, "0-status", (int32_t)WIFI_SETUP);
  nvs_commit(my_nvs_handle);

  CurrentStatus = WIFI_SETUP;
  wm.resetSettings();

  delay(5);
  esp_system_abort("restart_after_wakeup");

}


void SleepSave(int seconds){
  // IMPORTANT: Connect D0(GPIO-16) to RST after programing. This will reset the device after waking up (easy wifi/device restart)
  #ifdef DEBUG
    Serial.println("Will sleep now");
  #else
       delay(5);
    #endif
  //Deep-sleep for 9 seconds, and then wake up
  esp_set_deep_sleep_wake_stub(restart_after_wakeup);

  WiFi.disconnect(true);
  adc_power_off();

  esp_wifi_stop();

  //ESP.deepSleep(seconds*1000000);
  esp_deep_sleep(seconds*1000000);
  //system_deep_sleep_instant();
  // chip will not perform RF calibration after waking up
  // 1 -calib  ## 2 - no-calib
  //system_deep_sleep_set_option(2);

}


void non_lock_delay(unsigned long mili_seconds) {
  static unsigned long previousMillis = 0;
  static bool isWaiting = false;

  unsigned long currentMillis = millis();

  // Inicio de espera
  if (!isWaiting) {
    previousMillis = currentMillis;
    isWaiting = true;
  }

  while (isWaiting) {
    currentMillis = millis();
    
    // Verificar si el tiempo ha pasado
    if (currentMillis - previousMillis >= mili_seconds) {
      isWaiting = false; // Reiniciar la espera

    }

    // Permitir que el sistema operativo maneje tareas críticas
    delay(1); // Mantener el sistema operativo funcionando mientras se espera
  }
}


void splitString(const String &dataString, int *resultArray, int arraySize) {
  // Utilizar strtok para dividir la cadena en tokens basados en el delimitador '|'
  char *token = strtok(const_cast<char*>(dataString.c_str()), "|");

  // Iterar a través de los tokens y convertirlos en enteros
  int i = 0;
  while (token != NULL && i < arraySize) {
    // Utilizar atoi para convertir el token en un entero
    resultArray[i] = atoi(token);

    // Obtener el siguiente token
    token = strtok(NULL, "|");

    // Incrementar el índice
    i++;
  }
}


String urlEncode(String str) {
  String encoded = "";
  char c;
  char hex[4]; // Para almacenar el formato %XX

  for (size_t i = 0; i < str.length(); i++) {
    c = str.charAt(i);

    // Codificar caracteres especiales según el estándar
    if (isalnum(c) || c == '-' || c == '_' || c == '.' || c == '~') {
      encoded += c; // Dejar caracteres seguros sin cambios
    } else {
      sprintf(hex, "%%%02X", c); // Convertir a %XX
      encoded += hex;
    }
  }

  return encoded;
}


bool HttpRegDevice(){

  // Check for successful connection
  if (WiFi.status() == WL_CONNECTED) {
    #ifdef DEBUG
      Serial.println("Connected to WiFi");
    #else
       delay(5);
    #endif

    long timeout = 15000;

    HTTPClient https;
    https.setTimeout(timeout);
    https.setConnectTimeout(timeout);

    #ifdef DEBUG
      Serial.print("[HTTPS] begin...\n");
    #else
       delay(5);
    #endif


    char urlout[355];

    String email_encoded = urlEncode(email);
    // we are going to start here
    strcpy(urlout, host_link_url);
    strcat(urlout, "?key=");
    strcat(urlout, api_key);
    strcat(urlout, "&email=");
    strcat(urlout, email_encoded.c_str());



    if (https.begin(urlout)) {  // HTTPS

      //https.setVerify .setVerify(true);
      https.setReuse(false);

      // Add a custom HTTP header (replace "Your-Header" and "Header-Value" with your actual header and value)
      https.addHeader("FW-Version", (String)FIRMW_VER);
      https.addHeader("RSSI", (String)rssi);

      https.setTimeout(timeout);

      // prepare to read response headers
      const char *headerKeys[] = {"fw-version", "wpl-key"}; // Agrega todas las claves de los encabezados que deseas recopilar
      const size_t headerKeysCount = sizeof(headerKeys) / sizeof(headerKeys[0]);
      // Recopila las cabeceras HTTP especificadas
      https.collectHeaders(headerKeys, headerKeysCount);

      // start connection and send HTTP header
      int httpCode = https.GET();

      // httpCode will be negative on error
      if (httpCode > 0) {
        // HTTP header has been send and Server response header has been handled

        #ifdef DEBUG
          Serial.printf("[HTTPS] GET... code: %d\n", httpCode);
        #else
          delay(5);
        #endif

        // file found at server
        if (httpCode == HTTP_CODE_OK || httpCode == HTTP_CODE_MOVED_PERMANENTLY) {

          String payload = https.getString();

          #ifdef DEBUG
            Serial.print("response payload: ");
            Serial.println(payload);
          #else
            delay(5);
          #endif

          if(payload == "OK"){

            String latest_relay_fw = https.header("fw-version");
            String wlp_key = https.header("wpl-key");

            #ifdef DEBUG
              Serial.print("assigned wpl-key: ");
              Serial.println(wlp_key);
              Serial.print("Old api_key: ");
              Serial.println(api_key);
            #endif

            if(wlp_key.length() >= 7)
            {
                strcpy(api_key, wlp_key.c_str());
                nvs_set_str(my_nvs_handle, "PrivateKey", api_key);
                nvs_commit(my_nvs_handle);
                delay(5);
            }
            #ifdef DEBUG
              else{
                Serial.println("Invalid key status");
              }
            #endif
            

          }

          https.end();
          return true;

        }
      } else {
        #ifdef DEBUG
          Serial.printf("[HTTPS] GET... failed, error: %s\n", https.errorToString(httpCode).c_str());
        #else
          delay(5);
        #endif
        https.end();
        return false;
      }

    } else {
      #ifdef DEBUG
        Serial.printf("[HTTPS] Unable to connect\n");
      #else
       delay(5);
    #endif
      return false;
    }

  } else {
    #ifdef DEBUG
      Serial.println("Failed to connect to WiFi");
    #else
       delay(5);
    #endif
  }
  return false;
}


bool HttpSendInfo(int distance, float LastVoltage){

  // Check for successful connection
  if (WiFi.status() == WL_CONNECTED) {
    #ifdef DEBUG
      Serial.println("Connected to WiFi");
    #else
       delay(5);
    #endif

    long timeout = 15000;

    HTTPClient https;
    https.setTimeout(timeout);
    https.setConnectTimeout(timeout);

    #ifdef DEBUG
      Serial.print("[HTTPS] begin...\n");
    #else
       delay(5);
    #endif

    char dist_str[10];
    itoa(distance, dist_str, 10);

    char volt_str[10];
    int reg_volt = round(LastVoltage*100);
    itoa(reg_volt, volt_str, 10);


    char urlout[255];
    // we are going to start here
    strcpy(urlout, host_url);
    strcat(urlout, "?key=");
    strcat(urlout, api_key);
    strcat(urlout, "&distance=");
    strcat(urlout, dist_str);
    strcat(urlout, "&voltage=");
    strcat(urlout, volt_str);


    if (https.begin(urlout)) {  // HTTPS

      //https.setVerify .setVerify(true);
      https.setReuse(false);

      // Add a custom HTTP header (replace "Your-Header" and "Header-Value" with your actual header and value)
      https.addHeader("FW-Version", (String)FIRMW_VER);
      https.addHeader("RSSI", (String)rssi);

      https.setTimeout(timeout);

      // prepare to read response headers
      const char *headerKeys[] = {"fw-version", "wpl"}; // Agrega todas las claves de los encabezados que deseas recopilar
      const size_t headerKeysCount = sizeof(headerKeys) / sizeof(headerKeys[0]);
      // Recopila las cabeceras HTTP especificadas
      https.collectHeaders(headerKeys, headerKeysCount);

      // start connection and send HTTP header
      int httpCode = https.GET();

      // httpCode will be negative on error
      if (httpCode > 0) {
        // HTTP header has been send and Server response header has been handled

        #ifdef DEBUG
          Serial.printf("[HTTPS] GET... code: %d\n", httpCode);
        #else
          delay(5);
        #endif

        // file found at server
        if (httpCode == HTTP_CODE_OK || httpCode == HTTP_CODE_MOVED_PERMANENTLY) {

          String payload = https.getString();

          #ifdef DEBUG
            Serial.print("response payload: ");
            Serial.println(payload);
          #else
            delay(5);
          #endif

          // Tamaño del array para almacenar los valores
          const int arraySize = 5;
          int values[arraySize];
          // Llamar a la función para dividir la cadena y obtener los valores
          splitString(payload, values, arraySize);

          if(payload == "OK"){

            String latest_relay_fw = https.header("fw-version");
            String wlp_info = https.header("wpl");
            WIFI_POOL_TIME = wlp_info.toInt();

            int fw_ver = latest_relay_fw.toInt();
            if(DEV_MODE && FIRMW_VER < fw_ver){
                #ifdef DEBUG
                  Serial.println("new FW release");
                #else
                  delay(5);
                #endif
                updateFirmware(fw_ver);
            }

          }

          https.end();
          return true;

        }
      } else {
        #ifdef DEBUG
          Serial.printf("[HTTPS] GET... failed, error: %s\n", https.errorToString(httpCode).c_str());
        #else
          delay(5);
        #endif
        https.end();
        return false;
      }

    } else {
      #ifdef DEBUG
        Serial.printf("[HTTPS] Unable to connect\n");
      #else
       delay(5);
      #endif
      return false;
    }

  } else {
    #ifdef DEBUG
      Serial.println("Failed to connect to WiFi");
    #else
       delay(5);
    #endif
  }
  return false;
}

bool SetupResetWifi(){

  //WiFi.setTxPower(WIFI_POWER_8_5dBm);
  WiFi.mode(WIFI_AP); // explicitly set mode
  //WiFi.setTxPower(WIFI_POWER_8_5dBm);
  delay(5);

  //reset settings
  // wm.resetSettings();

  wm.setCaptivePortalEnable(true);

  std::vector<const char *> menu = {"wifi","restart","exit"};
  wm.setMenu(menu);

  // set configportal timeout 50 min
  wm.setConfigPortalTimeout(3000);
  wm.setSaveConnectTimeout(20);

  if (!wm.startConfigPortal(WIFI_NAME, WIFI_PASSW)) {

    #ifdef DEBUG
      Serial.println("failed to connect and hit timeout");
    #else
       delay(5);
    #endif

    nvs_set_i32(my_nvs_handle, "0-status", (int32_t)WIFI_SETUP);
    nvs_commit(my_nvs_handle);
    CurrentStatus = WIFI_SETUP;
    wm.resetSettings();

    delay(5);
    //reset and try again, or maybe put it to deep sleep
    esp_system_abort("restart_after_wakeup");
    delay(5);
  }

  #ifdef DEBUG
    Serial.println("connected success!");
  #else
       delay(5);
  #endif

  if(myStrlen(email) > 7){
    HttpRegDevice();
  }
  
  nvs_set_i32(my_nvs_handle, "0-status", (int32_t)WIFI);
  nvs_commit(my_nvs_handle);
  CurrentStatus = WIFI;

  delay(5);
  esp_system_abort("restart_after_wakeup");

}
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

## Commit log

2024-09-16 New SMD board tuning related to #3
2024-09-18 Missing debug comment at serial. Solution to #1 and #3
    [WiFiWaterLevelS1.ino]
2024-09-27 usbc update
    [Base.stl]
2024-11-09 3d case update
2024-11-26 Arduino libs
2024-11-29 Solar cell 20 degrees
    [SolarLid.stl, SolarSupport.stl]
2024-12-04 3d case updates
    [Base.stl, LidUSBPower.stl, SolarLid.stl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]
2024-12-08 pcb v4
2024-12-10 new case images
2024-12-27 Lid Mount Show
2024-12-30 model updates
    [USBC_CAP.stl]
2025-01-08 doc updates
    [LidSolarFusion.stl]
2025-02-04 Saving energy when user internet fails.
    [WiFiWaterLevelS1.ino]
2025-02-27 UART sensors support #4
2025-11-08 Update README with demo device details
    Added information about the demo device's performance and maintenance.

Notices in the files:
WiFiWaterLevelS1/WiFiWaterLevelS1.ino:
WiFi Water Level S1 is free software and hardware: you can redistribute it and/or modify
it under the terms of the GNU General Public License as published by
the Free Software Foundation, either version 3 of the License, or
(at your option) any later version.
